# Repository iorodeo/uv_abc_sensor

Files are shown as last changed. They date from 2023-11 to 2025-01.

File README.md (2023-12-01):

# IO Rodeo uv_abc_sensor

Hardware files for IO Rodeo's UV ABC light sensor (in development)

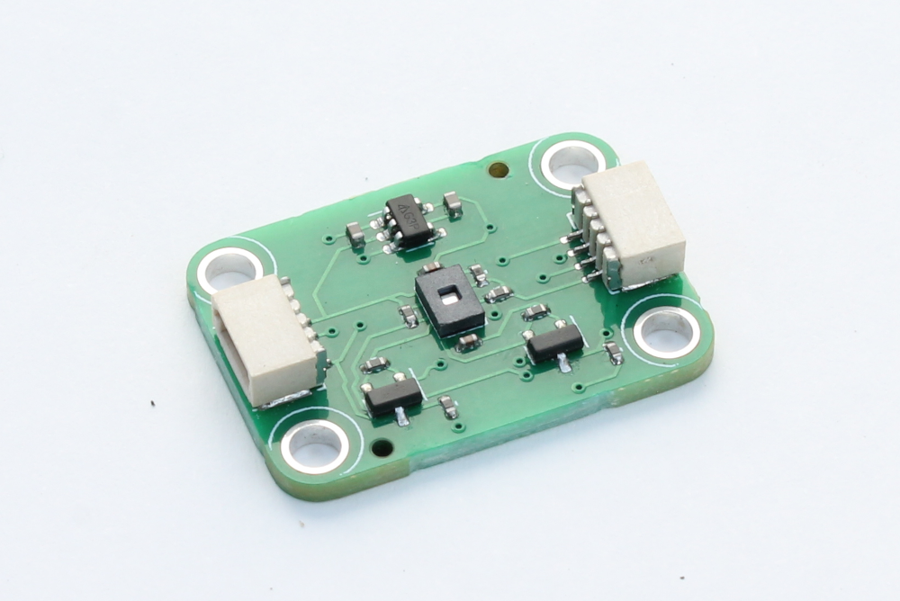
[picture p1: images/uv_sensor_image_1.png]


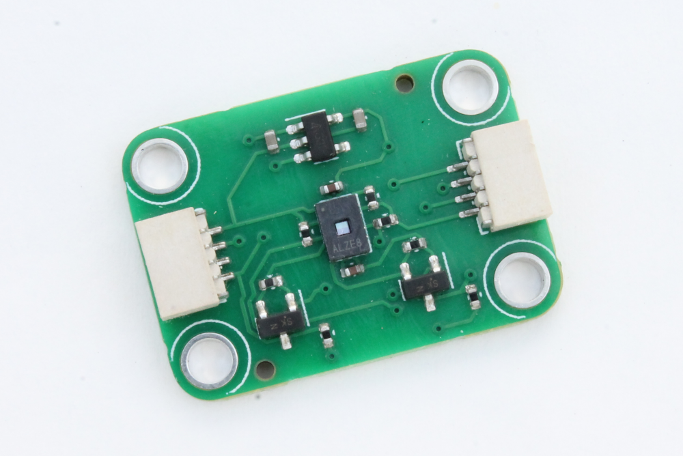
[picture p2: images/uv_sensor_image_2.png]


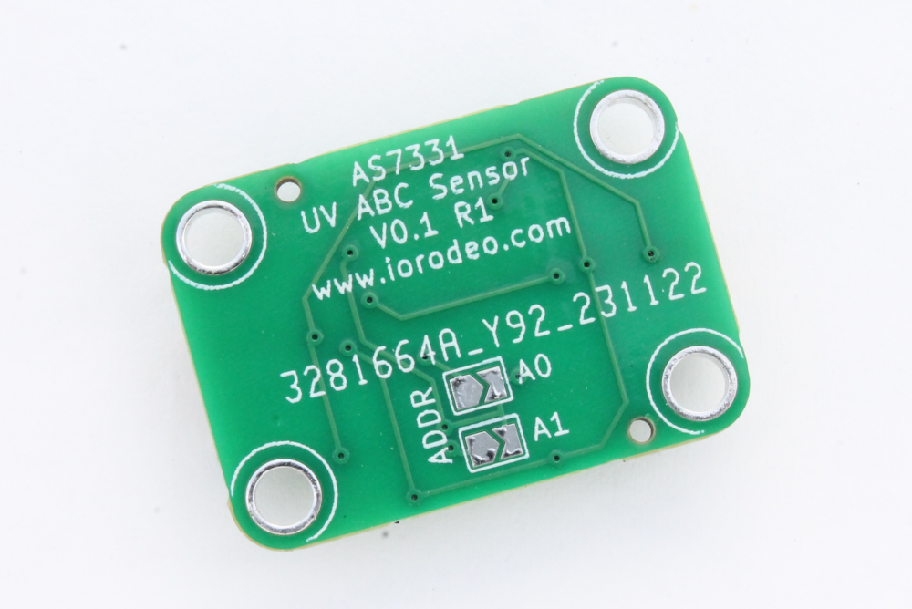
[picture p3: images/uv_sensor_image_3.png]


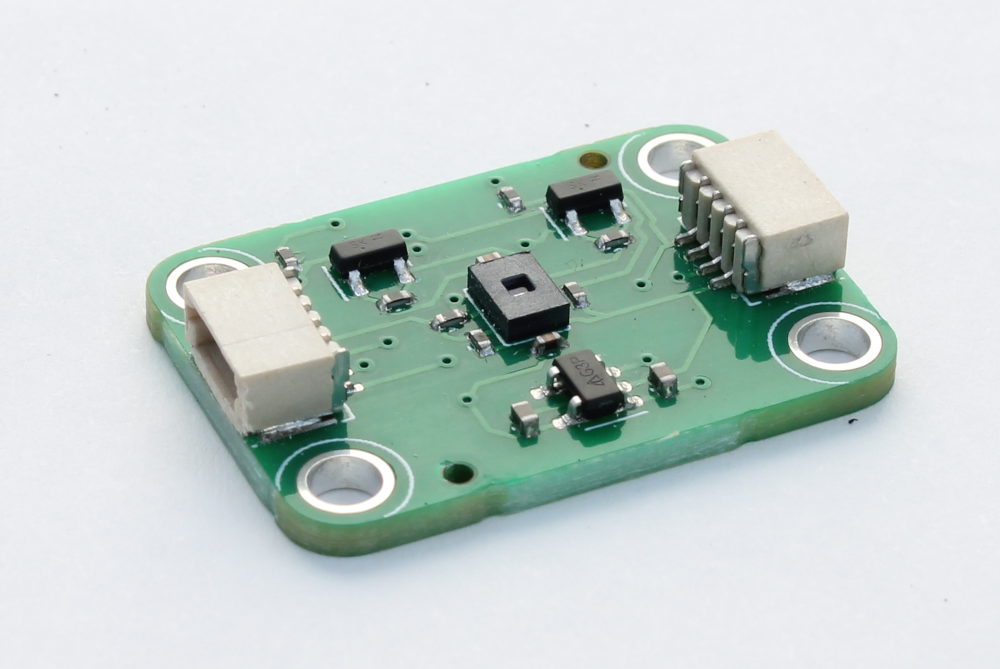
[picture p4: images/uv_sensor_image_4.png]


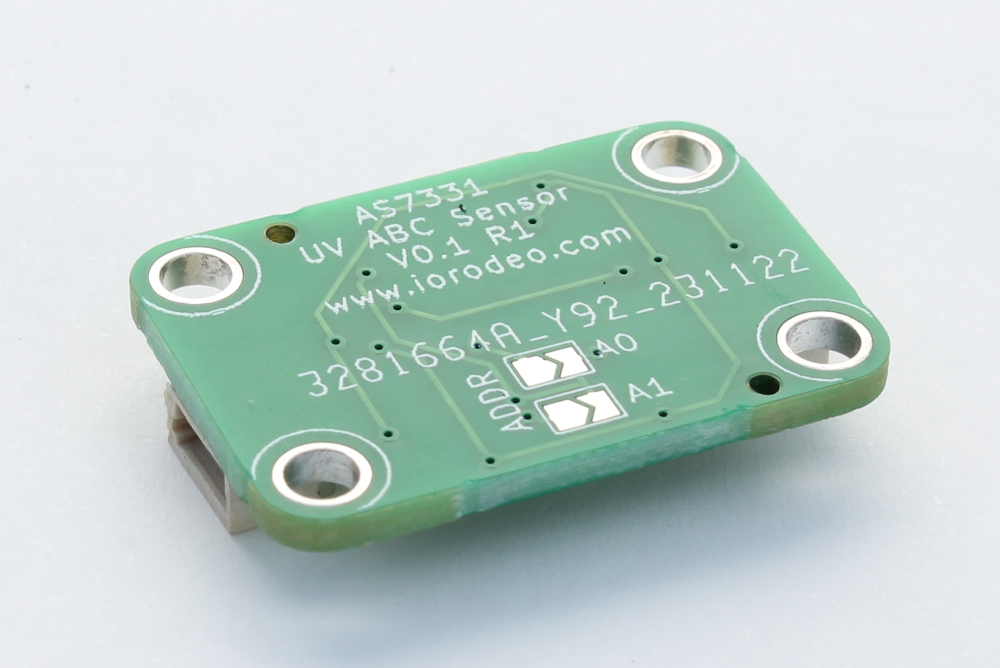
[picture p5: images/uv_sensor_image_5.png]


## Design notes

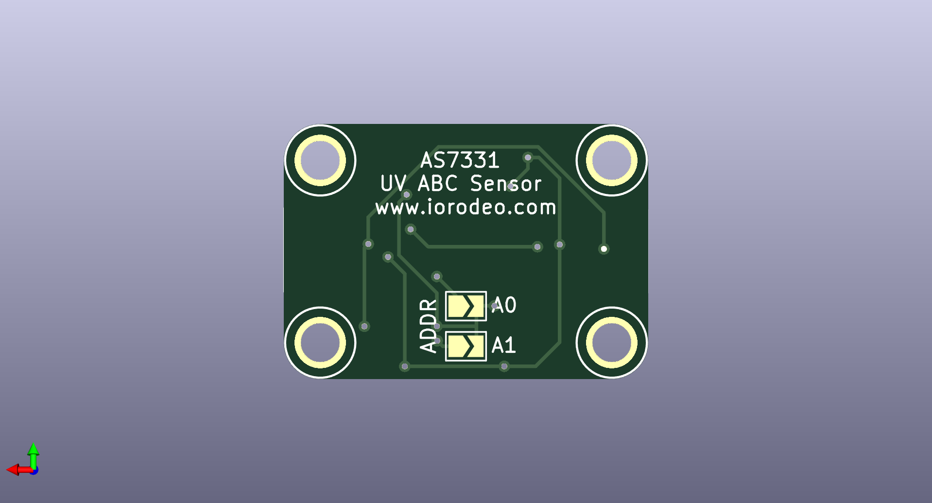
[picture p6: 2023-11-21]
images/uv_abc_sensor_back_1.png

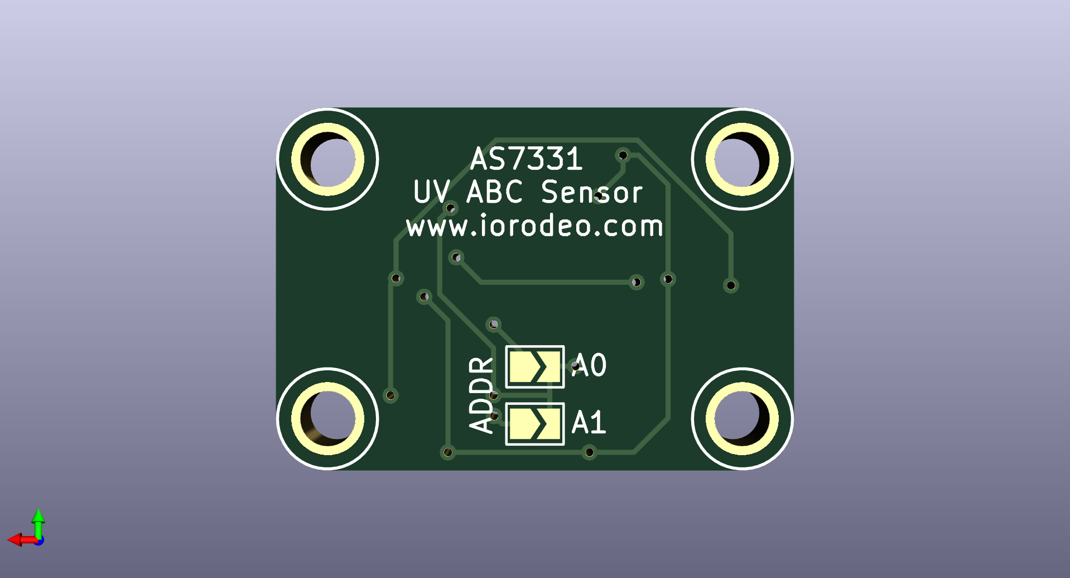
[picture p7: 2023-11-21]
images/uv_abc_sensor_back_2.png

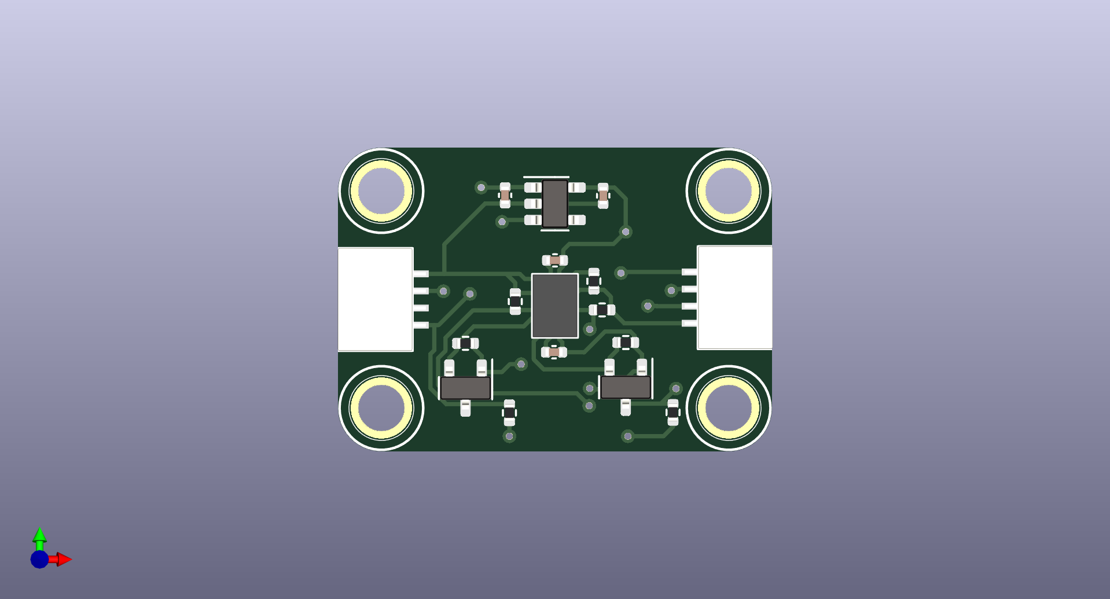
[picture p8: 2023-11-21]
images/uv_abc_sensor_front_1.png

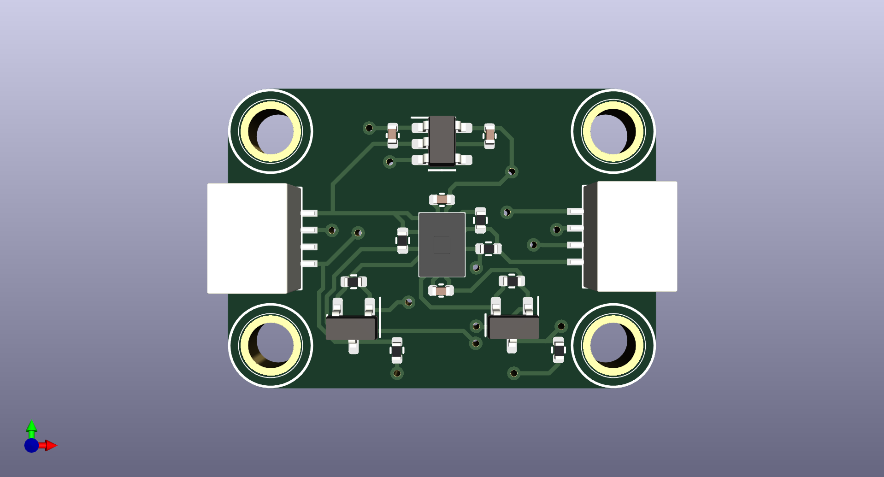
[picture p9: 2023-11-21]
images/uv_abc_sensor_front_2.png

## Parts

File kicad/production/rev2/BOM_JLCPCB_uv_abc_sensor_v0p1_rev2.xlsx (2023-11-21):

Comment | Designator | Footprint | LCSC Part #（optional） | Qty
100nF Ceramic Capacitor, 16V | C1,C2 | 0402 | C3012376 | 2
10uF Ceramic Capacitor, 10V | C3,C4 | 0402 | C315248 | 2
4-Pin Connector (BOOMELE) | J1 ,J2 | SMD,P=1mm | C145956 | 2
BSS138K N-Channel MOSFET | Q1,Q2 | SOT-23 | C255592 | 2
3.3M Resistor, 1% | R1 | 0402 | C270613 | 1
10k Resistor, 1% | R2,R3,R4,R5,R6,R7 | 0402 | C60490 | 6
AS7331, Spectral UVA/B/C Sensor | U1 | 16-TFLGA Module | C19189439 | 1
3.3V Linear Voltage Regulator | U2 | SOT-23-5 | C51118 | 1

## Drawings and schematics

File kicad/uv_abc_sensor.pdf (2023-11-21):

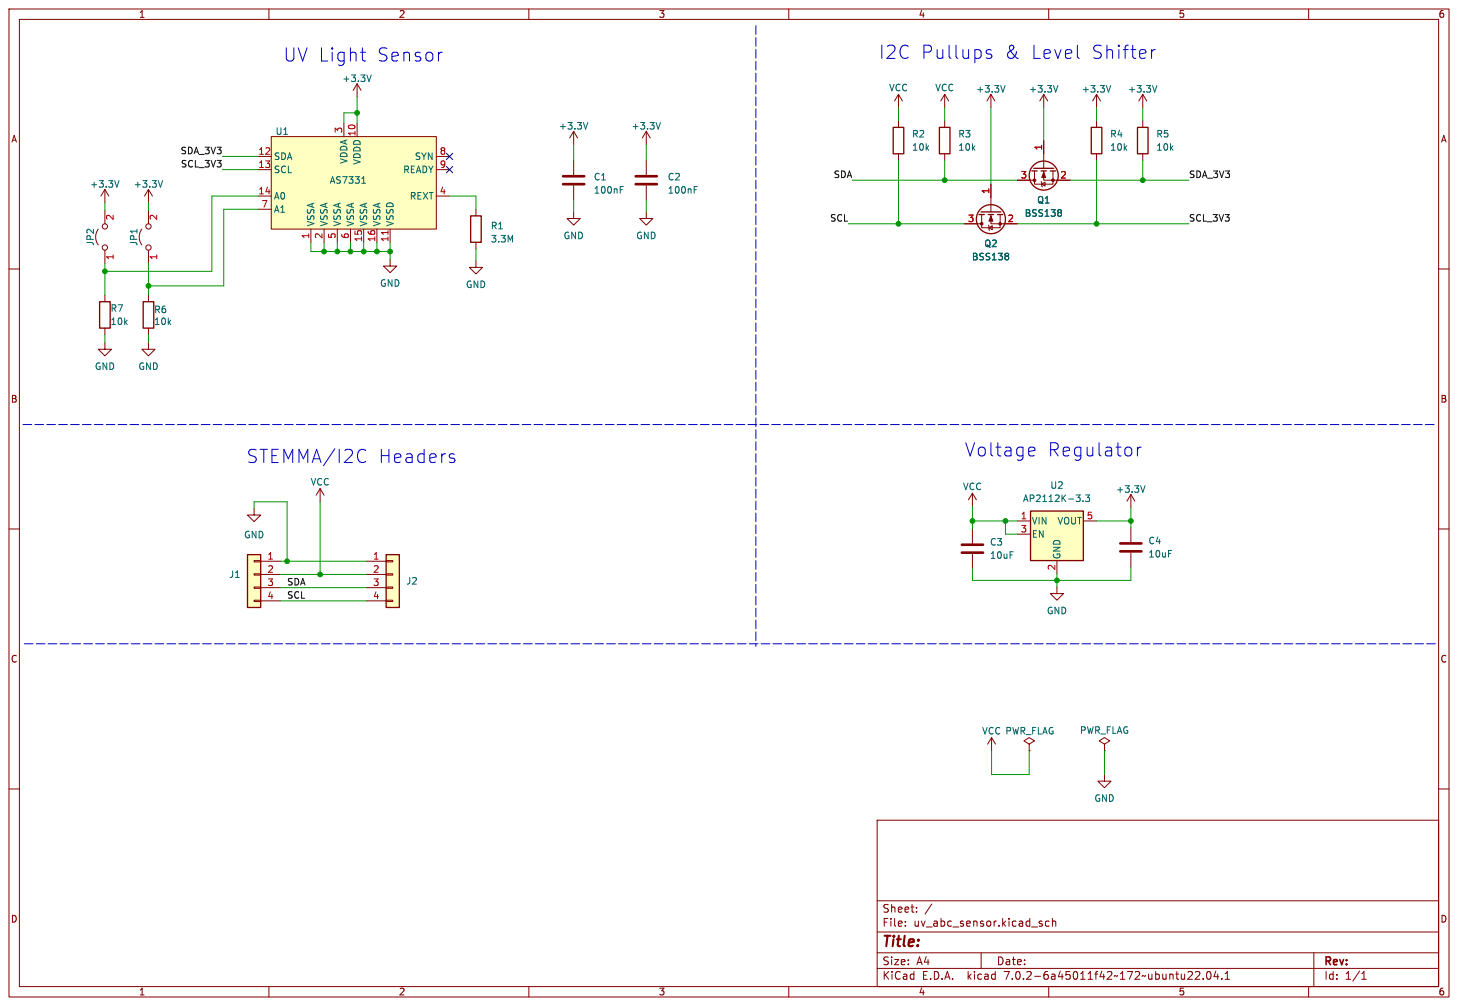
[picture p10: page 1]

1 VDDD 10 VSSD 11 SDA 12 SCL 13 A0 14 VSSA 15 VSSA 16 VSSA

Id: 1/1 Title: File: uv_abc_sensor.kicad_sch Sheet: /

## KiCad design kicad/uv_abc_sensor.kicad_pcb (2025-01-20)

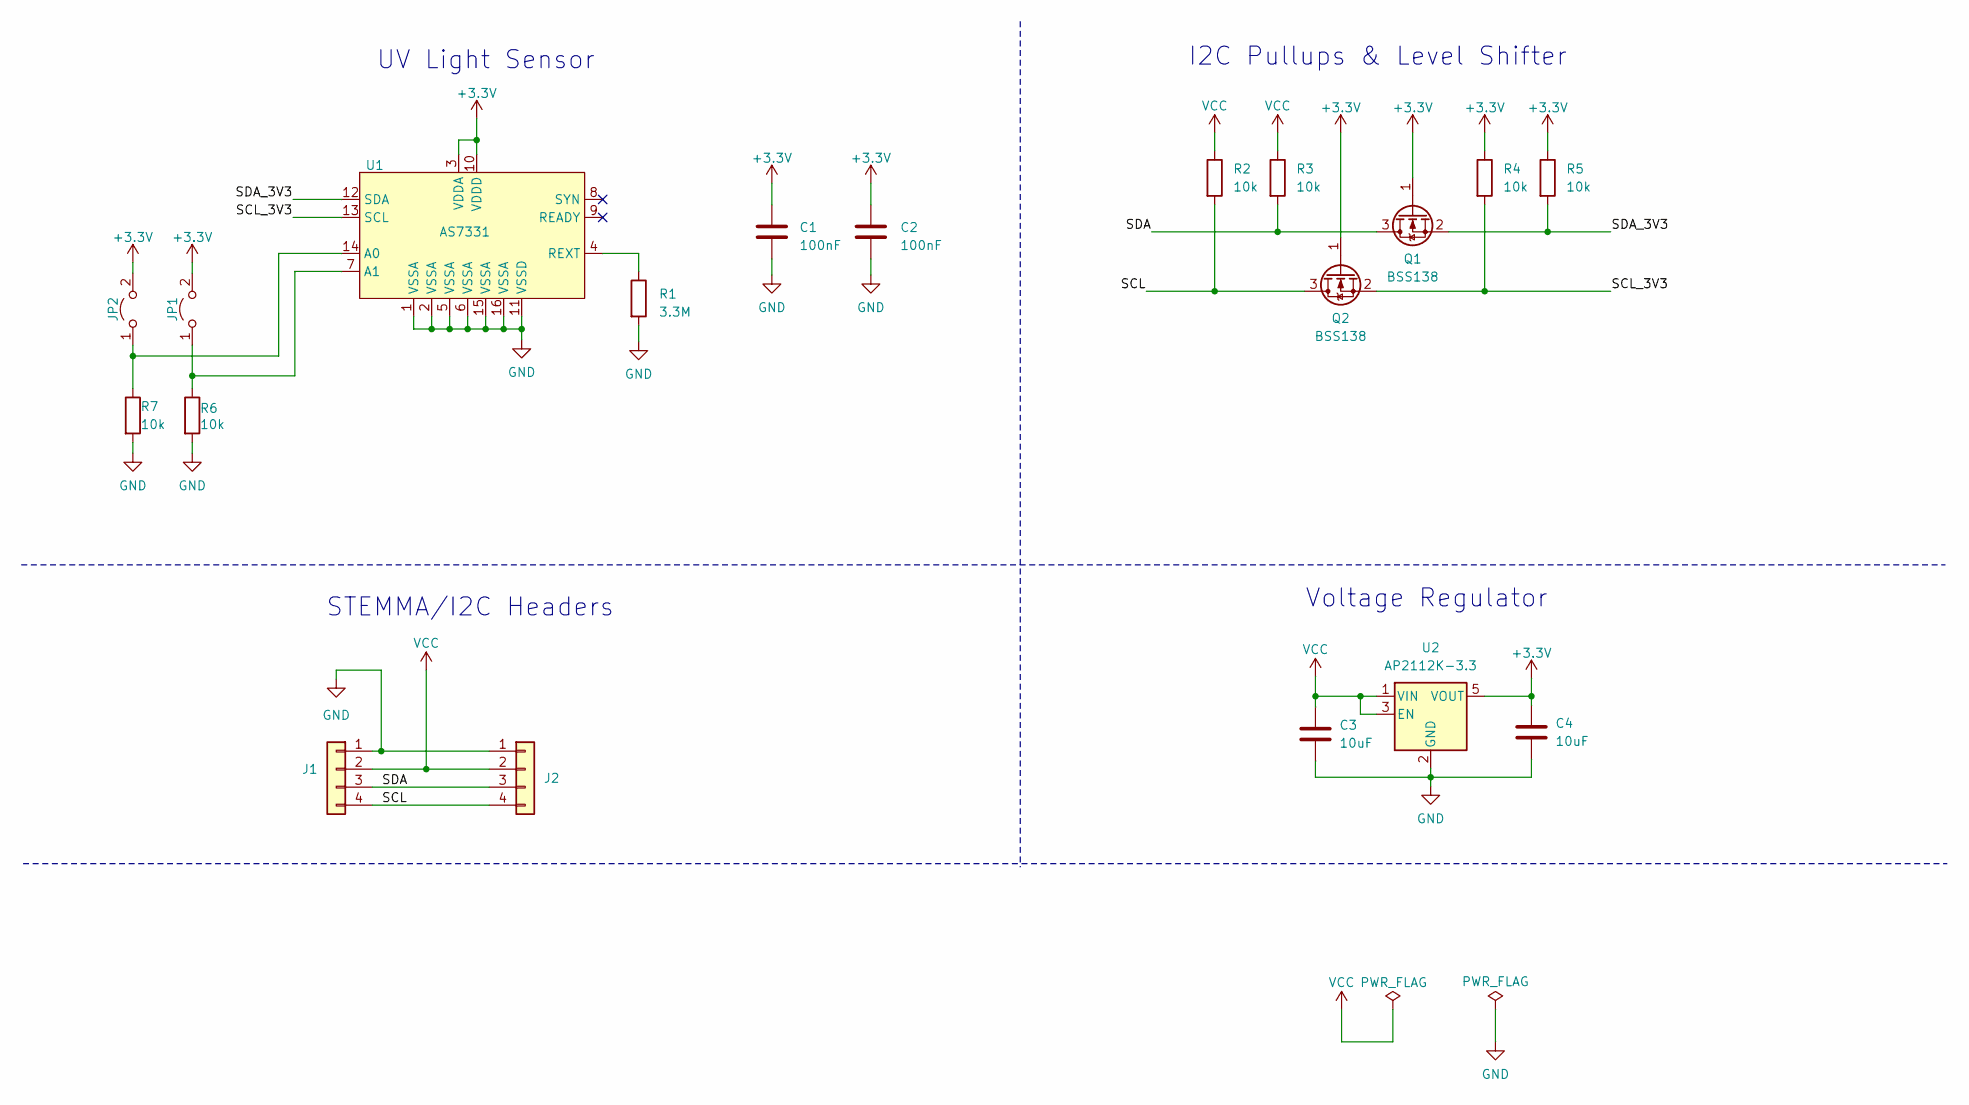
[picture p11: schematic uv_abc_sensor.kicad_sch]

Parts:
C1, C2: 100nF; C_0402_1005Metric
C3, C4: 10uF; C_0402_1005Metric
J1, J2: Conn_01x04; BOOMELE_SMD_SH_4PIN_RT
JP1, JP2: Jumper_2_Open; SolderJumper-2_P1.3mm_Open_TrianglePad1.0x1.5mm
Q1, Q2: BSS138; SOT-23
R1: 3.3M; R_0402_1005Metric
R2, R3, R4, R5, R6, R7: 10k; R_0402_1005Metric
U1: AS7331
U2: AP2112K-3.3; SOT-23-5

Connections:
+3.3V: C1.1, C2.1, C4.1, JP1.2 (B), JP2.2 (B), Q1.1 (G), Q2.1 (G), R4.1, R5.1, U1.3 (VDDA), U1.10 (VDDD), U2.5 (VOUT)
/SCL: J1.4, J2.4, Q2.3 (D), R2.2
/SCL_3V3: Q2.2 (S), R4.2, U1.13 (SCL)
/SDA: J1.3, J2.3, Q1.3 (D), R3.2
/SDA_3V3: Q1.2 (S), R5.2, U1.12 (SDA)
GND: C1.2, C2.2, C3.2, C4.2, J1.1, J2.1, R1.2, R6.2, R7.2, U1.1 (VSSA), U1.2 (VSSA), U1.5 (VSSA), U1.6 (VSSA), U1.11 (VSSD), U1.15 (VSSA), U1.16 (VSSA), U2.2 (GND)
unnamed: JP1.1 (A), R6.1, U1.7 (A1)
unnamed: JP2.1 (A), R7.1, U1.14 (A0)
unnamed: R1.1, U1.4 (REXT)
VCC: C3.1, J1.2, J2.2, R2.1, R3.1, U2.1 (VIN), U2.3 (EN)

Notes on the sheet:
STEMMA/I2C Headers
UV Light Sensor
Voltage Regulator
I2C Pullups & Level Shifter

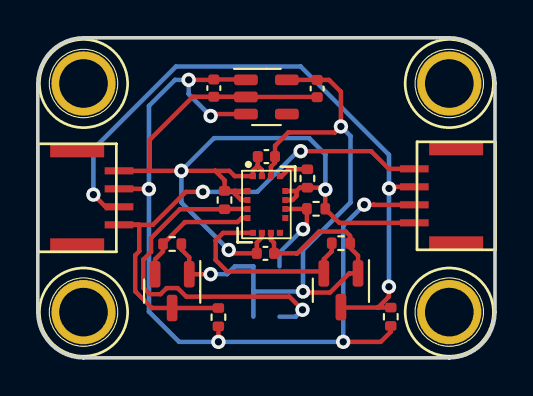
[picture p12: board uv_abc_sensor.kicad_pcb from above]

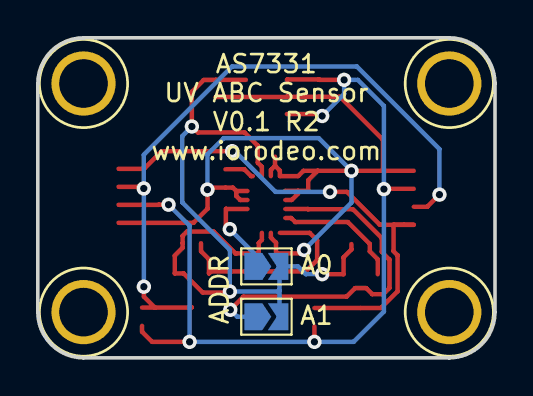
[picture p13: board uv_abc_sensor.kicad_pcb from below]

Board: 2 copper layers, 25.4 x 17.8 mm, 23 parts (2 on the bottom side), 10 nets.

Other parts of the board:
M1, M2, M3, M4: MountingHole_2.5mm_Pad

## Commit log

2023-10-04 Project creation.
    [uv_abc_sensor.kicad_pcb, uv_abc_sensor.kicad_sch]
2023-10-04 Finished initial schematic.
    [uv_abc_sensor.kicad_pcb, uv_abc_sensor.kicad_sch]
2023-10-05 Added .pdf of schematic.
    [uv_abc_sensor.kicad_sch]
2023-10-23 Worked on footprint assignment and PCB layout.
    [uv_abc_sensor.kicad_pcb, uv_abc_sensor.kicad_sch]
2023-10-24 More work on layout.
    [uv_abc_sensor.kicad_pcb]
2023-11-04 Worked on layout and routing.
    [uv_abc_sensor.kicad_pcb]
2023-11-06 Finished initial layout and routing.
    [uv_abc_sensor.dsn, uv_abc_sensor.kicad_pcb]
2023-11-21 Added production files.
    [BOM_JLCPCB_uv_abc_sensor_v0p1_rev1.xlsx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]
2023-12-01 Added images of prototype.
2025-01-20 Completed v0.1 rev2 of the sensor design.
    Modified as7331 footprint to (hopefully) descrease error rate. Made
    pads slightly larger. Also, removed all traces directly under the IC.
    [BOM_JLCPCB_uv_abc_sensor_v0p1_rev2.xlsx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]
